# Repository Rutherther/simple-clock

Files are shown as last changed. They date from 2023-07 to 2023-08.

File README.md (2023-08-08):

# Simple clock
This is just a small project that aims to make a simple clock, using STM32F103C8T6.
The clock will be shown on a seven segment display. There will be multiple modes to show
on the clock display.

## HW
STM32F103C8T6 is used as the _brains_. It has RTC that may be powered by CR2032 battery.
It's connected to a USB header, allowing to communicate with a computer. The chip is capable
of being a device, only, not host.
There is a header with 3V3, SWDIO, SWCLK, GND to allow programming the chip using a tool such as STLink.
ASM1117-3.3 is used for stepping down from 5V to 3V3.
3V3 should not be connected whilst USB is connected as well. This would short output of the LDO to 3V3.
There is no protection!

There are 8 seven segment displays,
4 of them are blue, 4 of them are yellow, the whole display looks like this: Y.Y.BB:BBY.Y.
(Y for yellow digit, B for blue digit)
There are 4 LEDs and 4 buttons, the LEDs are next to the buttons, making each LED "associated" with a button.
That makes it possible to light up an LED next to button, if the button is pressed etc.

The digits of the seven segment display are connected to PNP transistors.
When pulling the pin connected to the transistor low, the digit is turned on.
The pins used may be connected to timers, and PWM may be utilized to set
brightness.
Segments get turned on by being low as well.

Mapping of pins to peripherals is documented in [pins](docs/pins.md).

## Features / Roadmap

- [x] Remember date, time
  - [x] Time
  - [x] Date
- [x] Set time and date using simple interface
- [x] Switch between view modes by button
- [x] Show time, date
- [x] Adjust brightness using PWM
- [x] Auto adjust brightness based on time
- [ ] Stopwatch
- [ ] USB communication
  - [ ] Set time, Get time
  - [ ] Show arbitrary text or number on the display
  - [ ] Start stopwatch
  
## Usage
The clock has two modes, default mode, and edit mode.
Default mode displays the current time, edit mode is
for editing the current time.

### Default mode
This is entered upon reset. Upon startup,
it displays only current time as hours and minutes.

First button may change the current view, there are
four views.
1. time - hours and minutes only
2. time - with seconds
3. time and date - hours, minutes, day in month and month
4. date - year, day in month and month

The second button switches to edit mode.

Third and fourth buttons change brightness.
The brightness is normally automatically adjusted
based on the current time set on the clock.
It may be temporarily changed using these buttons.
The change will last 30 minutes.
Third button decreases brightness, fourth increases it.

### Edit mode
In the edit mode, it's possible to change the time and date.
Upon entering edit mode, hours will be selected to be changed.

The currently selected field will blink. To select the next field,
the first button should be used. The order of the fields edited is:
hours, minutes, seconds, year, month, day.

To increment or decrement the current field, second and third
buttons should be used, respectively.

To save the time and date, fourth button does the job.
It may be pressed when editing any field.

When in the edit mode, the time is paused. If you enter the
edit mode by accident, the clock will probably get behind,
because a couple of seconds will pass before you exit the edit mode.

## Images of the clock
### Front, off
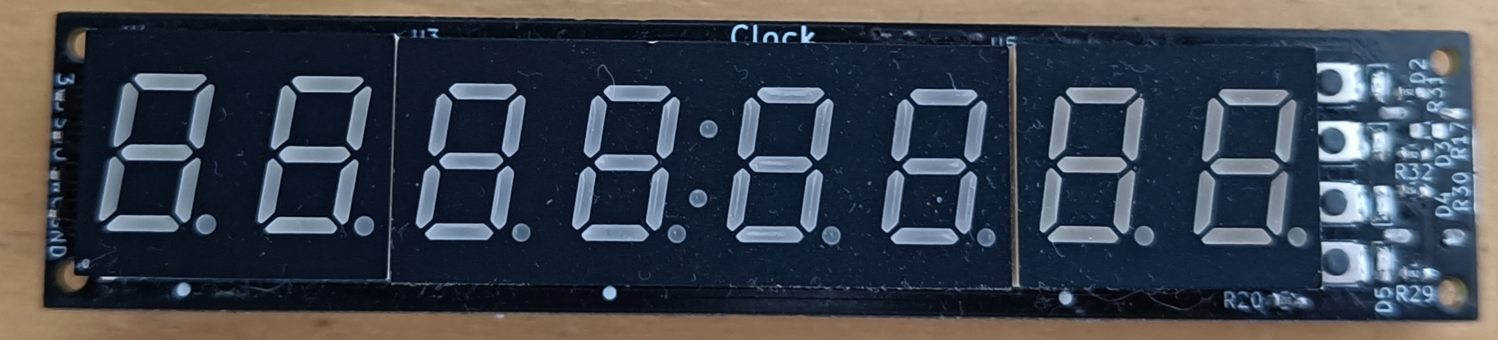
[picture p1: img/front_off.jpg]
Front, off


### Back
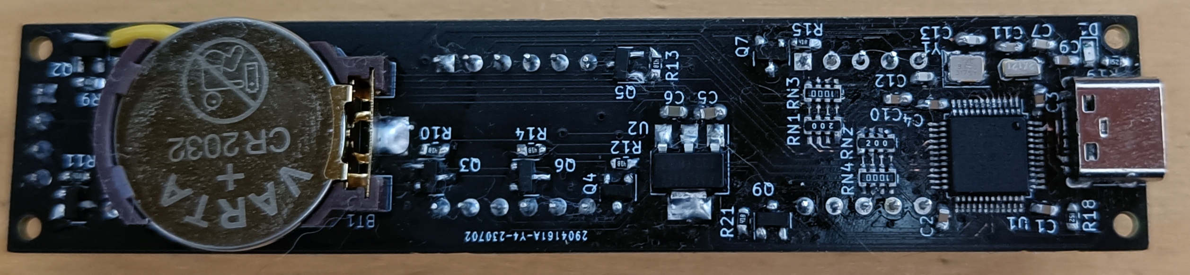
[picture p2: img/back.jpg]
Back


### Front, with seconds
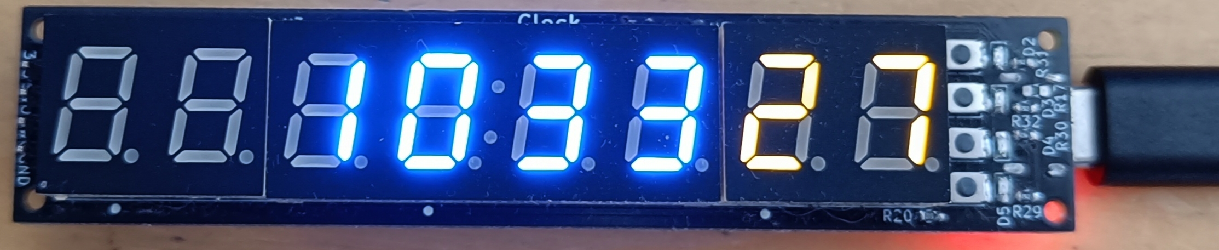
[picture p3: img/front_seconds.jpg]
Front, with seconds


### Front, with clock and date
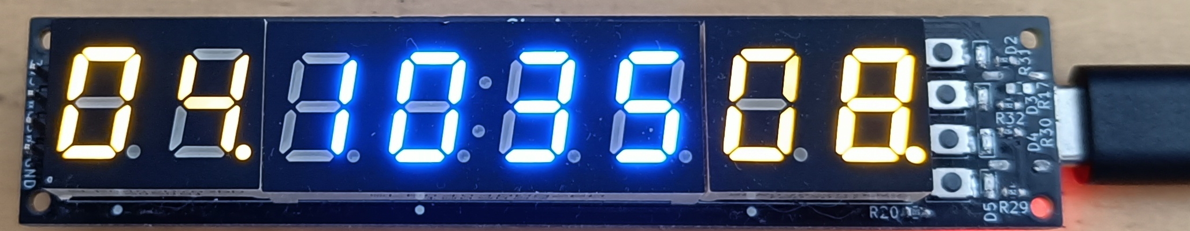
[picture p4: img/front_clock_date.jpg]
Front, clock and date


## What's next
Unfortunately, I did not solder the USB correctly on my board, so I cannot
currently test sending and receiving data using the USB, that is the reason
why the current program does not even support USB. In the future, the firmware
should support USB communication and a program for a computer should be made,
with some kind of CLI for communication with the board.

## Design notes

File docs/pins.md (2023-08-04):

# Pin mapping

## LEDs
LED1 PB12
LED2 PB11
LED3 PB1
LED4 PB0

## Buttons
SW1 PB15
SW2 PB14
SW3 PB13
SW4 PC13

## Seven segment display
The display pins are supposed to all be open-drains.
Individual segment is lit up by putting both the digit and segment on.
Only one digit at a time is supposed to be lit up, by turning
on multiple digits, it's possible.

DIG1 PA6  TIM3 CH1
DIG2 PA3  TIM2 CH4
DIG3 PA7  TIM3 CH2
DIG4 PA8  TIM1 CH1
DIG5 PA9  TIM1 CH2
DIG6 PA2  TIM2 CH3
DIG7 PA10 TIM1 CH3
DIG8 PA1  TIM2 CH2

A PB10
B PB2
C PB8
D PB6
E PB9
F PB3
G PB4
DP PB7

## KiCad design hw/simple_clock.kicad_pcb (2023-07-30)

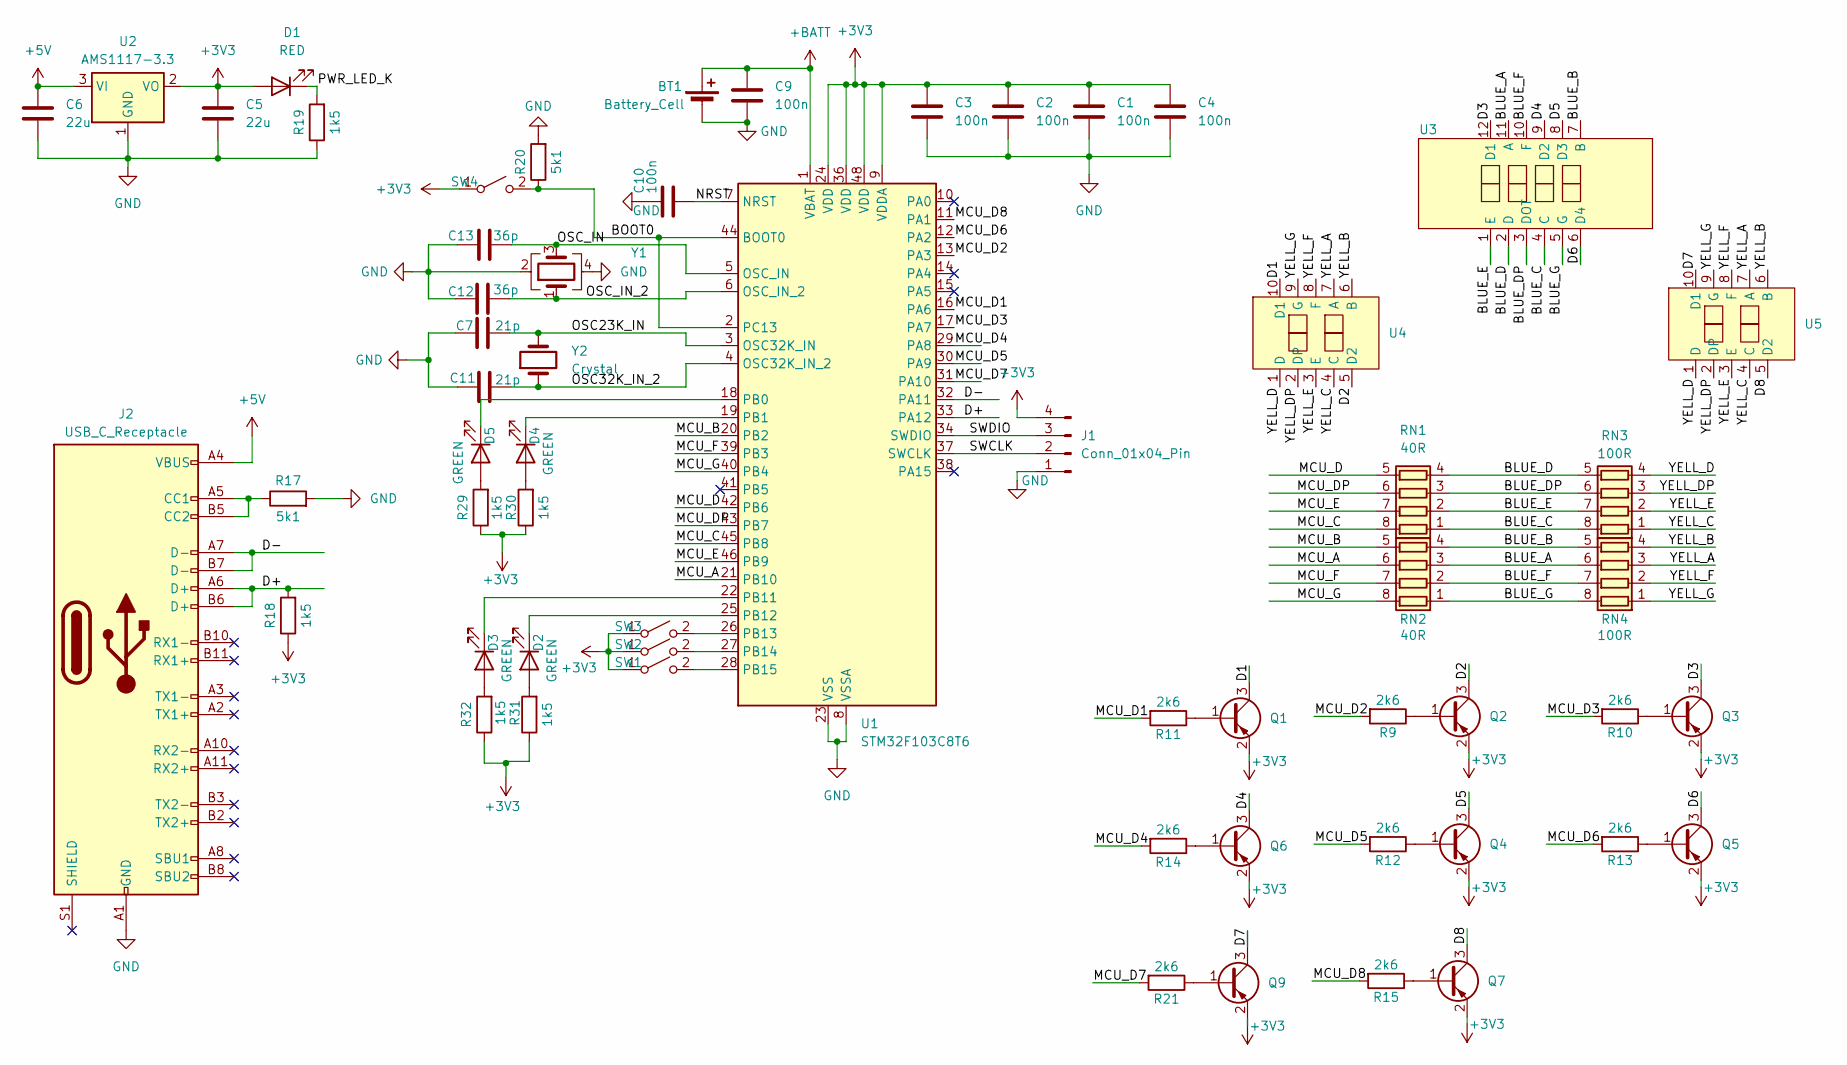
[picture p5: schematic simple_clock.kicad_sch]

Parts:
BT1: Battery_Cell; Q&J BS-8-1
C1, C2, C3, C4, C9, C10: 100n; C_0603_1608Metric
C5, C6: 22u; C_0603_1608Metric
C7, C11: 21p; C_0603_1608Metric
C12, C13: 36p; C_0603_1608Metric
D1: RED; LED_0603_1608Metric
D2, D3, D4, D5: GREEN; LED_0603_1608Metric
J1: Conn_01x04_Pin; PinHeader_1x04_P2.54mm_Vertical
J2: USB_C_Receptacle; USB_C_Receptacle_XKB_U262-16XN-4BVC11
Q1, Q2, Q3, Q4, Q5, Q6, Q7, Q9: Q_PNP_BEC; SOT-23
R9, R10, R11, R12, R13, R14, R15, R21: 2k6; R_0603_1608Metric
R17, R20: 5k1; R_0603_1608Metric
R18, R19, R29, R30, R31, R32: 1k5; R_0603_1608Metric
RN1, RN2: 40R; R_Array_Concave_4x0603
RN3, RN4: 100R; R_Array_Concave_4x0603
SW1, SW2, SW3, SW4: SW_SPST; TS-1088-AR02016
U1: STM32F103C8T6; LQFP-48_7x7mm_P0.5mm
U2: AMS1117-3.3; SOT-223-3_TabPin2
U3: SLR0404DBA2BD
U4, U5: SLR0402DYA3BD
Y1: Crystal_GND24; Crystal_SMD_3225-4Pin_3.2x2.5mm
Y2: Crystal; Crystal_SMD_3215-2Pin_3.2x1.5mm

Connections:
+3V3: C1.1, C2.1, C3.1, C4.1, C5.1, D1.2 (A), J1.4, Q1.2 (E), Q2.2 (E), Q3.2 (E), Q4.2 (E), Q5.2 (E), Q6.2 (E), Q7.2 (E), Q9.2 (E), R18.1, R29.1, R30.1, R31.1, R32.1, SW1.1 (A), SW2.1 (A), SW3.1 (A), SW4.1 (A), U1.9 (VDDA), U1.24 (VDD), U1.36 (VDD), U1.48 (VDD), U2.2 (VO)
+5V: C6.1, J2.A4 (VBUS), J2.A9 (VBUS), J2.B4 (VBUS), J2.B9 (VBUS), U2.3 (VI)
+BATT: BT1.1 (+), C9.1, U1.1 (VBAT)
/BLUE_A: RN2.3 (R3.1), RN4.6 (R3.2), U3.11 (A)
/BLUE_B: RN2.4 (R4.1), RN4.5 (R4.2), U3.7 (B)
/BLUE_C: RN1.1 (R1.1), RN3.8 (R1.2), U3.4 (C)
/BLUE_D: RN1.4 (R4.1), RN3.5 (R4.2), U3.2 (D)
/BLUE_DP: RN1.3 (R3.1), RN3.6 (R3.2), U3.3 (DOT)
/BLUE_E: RN1.2 (R2.1), RN3.7 (R2.2), U3.1 (E)
/BLUE_F: RN2.2 (R2.1), RN4.7 (R2.2), U3.10 (F)
/BLUE_G: RN2.1 (R1.1), RN4.8 (R1.2), U3.5 (G)
/BOOT0: R20.1, SW4.2 (B), U1.2 (PC13), U1.44 (BOOT0)
/D1: Q1.3 (C), U4.10 (D1)
/D2: Q2.3 (C), U4.5 (D2)
/D3: Q3.3 (C), U3.12 (D1)
/D4: Q6.3 (C), U3.9 (D2)
/D5: Q4.3 (C), U3.8 (D3)
/D6: Q5.3 (C), U3.6 (D4)
/D7: Q9.3 (C), U5.10 (D1)
/D8: Q7.3 (C), U5.5 (D2)
/D+: J2.A6 (D+), J2.B6 (D+), R18.2, U1.33 (PA12)
/D-: J2.A7 (D-), J2.B7 (D-), U1.32 (PA11)
/MCU_A: RN2.6 (R3.2), U1.21 (PB10)
/MCU_B: RN2.5 (R4.2), U1.20 (PB2)
/MCU_C: RN1.8 (R1.2), U1.45 (PB8)
/MCU_D: RN1.5 (R4.2), U1.42 (PB6)
/MCU_D1: R11.2, U1.16 (PA6)
/MCU_D2: R9.2, U1.13 (PA3)
/MCU_D3: R10.2, U1.17 (PA7)
/MCU_D4: R14.2, U1.29 (PA8)
/MCU_D5: R12.2, U1.30 (PA9)
/MCU_D6: R13.2, U1.12 (PA2)
/MCU_D7: R21.2, U1.31 (PA10)
/MCU_D8: R15.2, U1.11 (PA1)
/MCU_DP: RN1.6 (R3.2), U1.43 (PB7)
/MCU_E: RN1.7 (R2.2), U1.46 (PB9)
/MCU_F: RN2.7 (R2.2), U1.39 (PB3)
/MCU_G: RN2.8 (R1.2), U1.40 (PB4)
/NRST: C10.2, U1.7 (NRST)
/OSC23K_IN: C7.2, U1.3 (OSC32K_IN), Y2.2
/OSC32K_IN_2: C11.2, U1.4 (OSC32K_IN_2), Y2.1
/OSC_IN_2: C12.2, U1.6 (OSC_IN_2), Y1.1
/PWR_LED_K: D1.1 (K), R19.2
/SWCLK: J1.2, U1.37 (SWCLK)
/SWDIO: J1.3, U1.34 (SWDIO)
/YELL_A: RN4.3 (R3.1), U4.7 (A), U5.7 (A)
/YELL_B: RN4.4 (R4.1), U4.6 (B), U5.6 (B)
/YELL_C: RN3.1 (R1.1), U4.4 (C), U5.4 (C)
/YELL_D: RN3.4 (R4.1), U4.1 (D), U5.1 (D)
/YELL_DP: RN3.3 (R3.1), U4.2 (DP), U5.2 (DP)
/YELL_E: RN3.2 (R2.1), U4.3 (E), U5.3 (E)
/YELL_F: RN4.2 (R2.1), U4.8 (F), U5.8 (F)
/YELL_G: RN4.1 (R1.1), U4.9 (G), U5.9 (G)
GND: BT1.2 (-), C1.2, C2.2, C3.2, C4.2, C5.2, C6.2, C7.1, C9.2, C10.1, C11.1, C12.1, C13.1, J1.1, J2.A1 (GND), J2.A12 (GND), J2.B1 (GND), J2.B12 (GND), R17.2, R19.1, R20.2, U1.8 (VSSA), U1.23 (VSS), U1.35 (VSS), U1.47 (VSS), U2.1 (GND), Y1.2, Y1.4
unnamed: D2.2 (A), R31.2
unnamed: D2.1 (K), U1.25 (PB12)
unnamed: D3.2 (A), R32.2
unnamed: D3.1 (K), U1.22 (PB11)
unnamed: D4.2 (A), R30.2
unnamed: D4.1 (K), U1.19 (PB1)
unnamed: D5.2 (A), R29.2
unnamed: D5.1 (K), U1.18 (PB0)
unnamed: J2.A5 (CC1), J2.B5 (CC2), R17.1
unnamed: Q1.1 (B), R11.1
unnamed: Q2.1 (B), R9.1
unnamed: Q3.1 (B), R10.1
unnamed: Q4.1 (B), R12.1
unnamed: Q5.1 (B), R13.1
unnamed: Q6.1 (B), R14.1
unnamed: Q7.1 (B), R15.1
unnamed: Q9.1 (B), R21.1
unnamed: SW1.2 (B), U1.28 (PB15)
unnamed: SW2.2 (B), U1.27 (PB14)
unnamed: SW3.2 (B), U1.26 (PB13)
unnamed: C13.2, U1.5 (OSC_IN), Y1.3

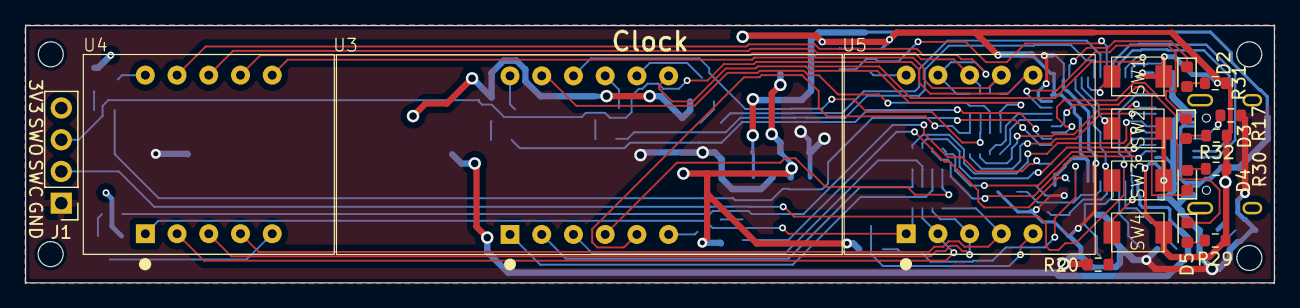
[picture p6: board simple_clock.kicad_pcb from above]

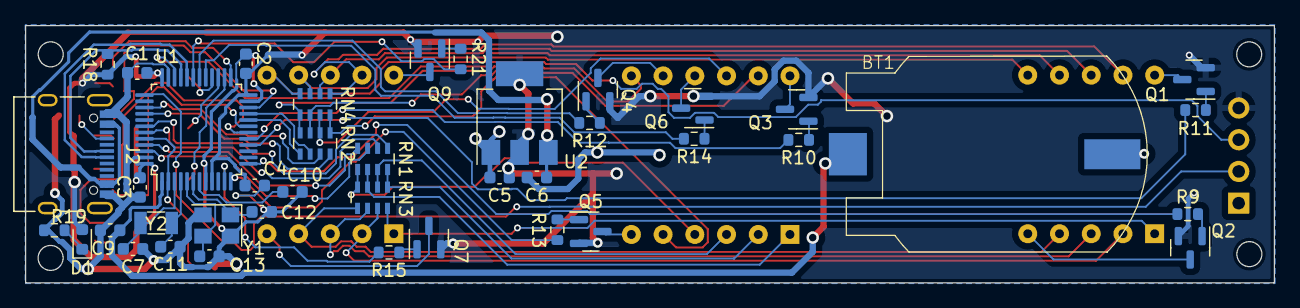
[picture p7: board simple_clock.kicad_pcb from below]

Board: 2 copper layers, 100.0 x 20.6 mm, 59 parts (41 on the bottom side), 75 nets.

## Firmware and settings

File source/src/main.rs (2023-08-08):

#![no_std]
#![no_main]
#![feature(alloc_error_handler)]
#![feature(variant_count)]
#![feature(adt_const_params)]

extern crate alloc;

pub mod brightness_manager;
pub mod button;
pub mod calendar;
pub mod clock_app;
pub mod clock_display;
pub mod clock_display_viewer;
pub mod clock_state;
pub mod count_down;
pub mod display;
pub mod linear_interpolation;
pub mod mono_timer;
pub mod number_digits;
pub mod seven_segments;
pub mod app_mode;

use alloc::boxed::Box;
use button::{ActiveHigh, Button, ButtonState};
use calendar::Calendar;
use clock_app::{ClockApp, ClockInterrupt};
use clock_display::{ClockDisplay, DisplayPart};
use clock_display_viewer::{ClockDisplayViewer, DisplayView};
use clock_state::ClockState;
use core::{alloc::Layout, cell::RefCell, convert::Infallible, panic::PanicInfo};
use cortex_m::asm::wfi;
use cortex_m_rt::entry;
use count_down::{CountDown, CountDowner};
use critical_section::Mutex;
use display::Display;
use embedded_alloc::Heap;
use embedded_hal::digital::v2::OutputPin;
use fugit::MicrosDurationU32;
use stm32f1xx_hal::{
    afio::MAPR,
    gpio::{Cr, Floating, Input, Pin},
    pac,
    pac::interrupt,
    prelude::*,
    rcc::Clocks,
    rtc::{
        RestoredOrNewRtc::{New, Restored},
        Rtc,
    },
    time::MonoTimer,
    timer::{Event, SysDelay, Tim1NoRemap, Tim2NoRemap, Tim3NoRemap, TimerExt},
};

use defmt_rtt as _;

#[global_allocator]
static HEAP: Heap = Heap::empty();

static APP: Mutex<RefCell<Option<ClockApp>>> = Mutex::new(RefCell::new(Option::None));

#[interrupt]
fn RTC() {
    critical_section::with(|cs| {
        let mut app = APP.borrow_ref_mut(cs);
        let app = app.as_mut().unwrap();

        app.interrupt(ClockInterrupt::Rtc);
    });
}

#[interrupt]
fn TIM4() {
    critical_section::with(|cs| {
        let mut app = APP.borrow_ref_mut(cs);
        let app = app.as_mut().unwrap();

        app.interrupt(ClockInterrupt::DisplayTimer);
    });
}

/// Puts given pins into open drain,
/// then makes PWM out of digit pins,
/// lastly, timer 4 is constructed for refreshing the display,
/// and ClockDisplayViewer is created.
fn init_segment_display(
    pb10: Pin<'B', 10, Input<Floating>>,
    pb2: Pin<'B', 2, Input<Floating>>,
    pb8: Pin<'B', 8, Input<Floating>>,
    pb6: Pin<'B', 6, Input<Floating>>,
    pb9: Pin<'B', 9, Input<Floating>>,
    pb3: Pin<'B', 3, Input<Floating>>,
    pb4: Pin<'B', 4, Input<Floating>>,
    pb7: Pin<'B', 7, Input<Floating>>,
    pa6: Pin<'A', 6, Input<Floating>>,
    pa3: Pin<'A', 3, Input<Floating>>,
    pa7: Pin<'A', 7, Input<Floating>>,
    pa8: Pin<'A', 8, Input<Floating>>,
    pa9: Pin<'A', 9, Input<Floating>>,
    pa2: Pin<'A', 2, Input<Floating>>,
    pa10: Pin<'A', 10, Input<Floating>>,
    pa1: Pin<'A', 1, Input<Floating>>,
    tim1: pac::TIM1,
    tim2: pac::TIM2,
    tim3: pac::TIM3,
    tim4: pac::TIM4,
    gpioa_crl: &mut Cr<'A', false>,
    gpioa_crh: &mut Cr<'A', true>,
    gpiob_crl: &mut Cr<'B', false>,
    gpiob_crh: &mut Cr<'B', true>,
    afio_mapr: &mut MAPR,
    clocks: &Clocks,
) -> ClockDisplayViewer {
    let a = pb10.into_open_drain_output(gpiob_crh);
    let b = pb2.into_open_drain_output(gpiob_crl);
    let c = pb8.into_open_drain_output(gpiob_crh);
    let d = pb6.into_open_drain_output(gpiob_crl);
    let e = pb9.into_open_drain_output(gpiob_crh);
    let f = pb3.into_open_drain_output(gpiob_crl);
    let g = pb4.into_open_drain_output(gpiob_crl);
    let dpp = pb7.into_open_drain_output(gpiob_crl);

    let dig1 = pa6.into_alternate_open_drain(gpioa_crl);
    let dig2 = pa3.into_alternate_open_drain(gpioa_crl);
    let dig3 = pa7.into_alternate_open_drain(gpioa_crl);
    let dig4 = pa8.into_alternate_open_drain(gpioa_crh);
    let dig5 = pa9.into_alternate_open_drain(gpioa_crh);
    let dig6 = pa2.into_alternate_open_drain(gpioa_crl);
    let dig7 = pa10.into_alternate_open_drain(gpioa_crh);
    let dig8 = pa1.into_alternate_open_drain(gpioa_crl);

    let pwm_freq = 2.kHz();
    let pins1 = (dig4, dig5, dig7);
    let pwm1 = tim1.pwm_hz::<Tim1NoRemap, _, _>(pins1, afio_mapr, pwm_freq, &clocks);

    let pins2 = (dig8, dig6, dig2);
    let pwm2 = tim2.pwm_hz::<Tim2NoRemap, _, _>(pins2, afio_mapr, pwm_freq, &clocks);

    let pins3 = (dig1, dig3);
    let pwm3 = tim3.pwm_hz::<Tim3NoRemap, _, _>(pins3, afio_mapr, pwm_freq, &clocks);

    let mut tim4 = tim4.counter_us(&clocks);
    tim4.listen(Event::Update);
    tim4.start(10.micros()).unwrap();

    let countdown: Box<dyn CountDown<Time = MicrosDurationU32> + Send> =
        Box::new(CountDowner::new(tim4));

    let (dig4, dig5, dig7) = pwm1.split();
    let (dig8, dig6, dig2) = pwm2.split();
    let (dig1, dig3) = pwm3.split();

    let display = Display::<8>::new(
        [
            Box::new(a),
            Box::new(b),
            Box::new(c),
            Box::new(d),
            Box::new(e),
            Box::new(f),
            Box::new(g),
            Box::new(dpp),
        ],
        [
            Box::new(dig1),
            Box::new(dig2),
            Box::new(dig3),
            Box::new(dig4),
            Box::new(dig5),
            Box::new(dig6),
            Box::new(dig7),
            Box::new(dig8),
        ],
        countdown,
    );

    let display = ClockDisplay::new(display);
    ClockDisplayViewer::new(display)
}

fn init_buttons(
    pb15: Pin<'B', 15, Input<Floating>>,
    pb14: Pin<'B', 14, Input<Floating>>,
    pb13: Pin<'B', 13, Input<Floating>>,
    pc13: Pin<'C', 13, Input<Floating>>,
    gpiob_crh: &mut Cr<'B', true>,
    gpioc_crh: &mut Cr<'C', true>,
) -> [Button<ActiveHigh>; 4] {
    let btn1 = Button::<ActiveHigh>::new(Box::new(pb15.into_pull_down_input(gpiob_crh)));
    let btn2 = Button::<ActiveHigh>::new(Box::new(pb14.into_pull_down_input(gpiob_crh)));
    let btn3 = Button::<ActiveHigh>::new(Box::new(pb13.into_pull_down_input(gpiob_crh)));
    let btn4 = Button::<ActiveHigh>::new(Box::new(pc13.into_pull_down_input(gpioc_crh)));

    [btn1, btn2, btn3, btn4]
}

fn init_leds<'a>(
    pb12: Pin<'B', 12, Input<Floating>>,
    pb11: Pin<'B', 11, Input<Floating>>,
    pb1: Pin<'B', 1, Input<Floating>>,
    pb0: Pin<'B', 0, Input<Floating>>,
    gpiob_crl: &mut Cr<'B', false>,
    gpiob_crh: &mut Cr<'B', true>,
) -> [Box<dyn OutputPin<Error = Infallible> + Send>; 4] {
    let led1 = pb12.into_open_drain_output(gpiob_crh);
    let led2 = pb11.into_open_drain_output(gpiob_crh);
    let led3 = pb1.into_open_drain_output(gpiob_crl);
    let led4 = pb0.into_open_drain_output(gpiob_crl);

    [
        Box::new(led1),
        Box::new(led2),
        Box::new(led3),
        Box::new(led4),
    ]
}

fn init_heap() {
    use core::mem::MaybeUninit;
    const HEAP_SIZE: usize = 512;
    static mut HEAP_MEM: [MaybeUninit<u8>; HEAP_SIZE] = [MaybeUninit::uninit(); HEAP_SIZE];
    unsafe { HEAP.init(HEAP_MEM.as_ptr() as usize, HEAP_SIZE) }
}

#[entry]
fn main() -> ! {
    init_heap();

    let cp = cortex_m::Peripherals::take().unwrap();
    let dp = pac::Peripherals::take().unwrap();

    let mut pwr = dp.PWR;
    let mut flash = dp.FLASH.constrain();
    let rcc = dp.RCC.constrain();
    let mut backup_domain = rcc.bkp.constrain(dp.BKP, &mut pwr);

    let clocks = rcc
        .cfgr
        .use_hse(8.MHz())
        .sysclk(24.MHz())
        .pclk1(24.MHz())
        .pclk2(24.MHz())
        .freeze(&mut flash.acr);

    let mut gpiob = dp.GPIOB.split();
    let mut gpioa = dp.GPIOA.split();
    let mut gpioc = dp.GPIOC.split();
    let mut afio = dp.AFIO.constrain();
    let (_, pb3, pb4) = afio.mapr.disable_jtag(gpioa.pa15, gpiob.pb3, gpiob.pb4);

    let leds = init_leds(
        gpiob.pb12,
        gpiob.pb11,
        gpiob.pb1,
        gpiob.pb0,
        &mut gpiob.crl,
        &mut gpiob.crh,
    );
    let btns = init_buttons(
        gpiob.pb15,
        gpiob.pb14,
        gpiob.pb13,
        gpioc.pc13,
        &mut gpiob.crh,
        &mut gpioc.crh,
    );

    let mut display = init_segment_display(
        gpiob.pb10,
        gpiob.pb2,
        gpiob.pb8,
        gpiob.pb6,
        gpiob.pb9,
        pb3,
        pb4,
        gpiob.pb7,
        gpioa.pa6,
        gpioa.pa3,
        gpioa.pa7,
        gpioa.pa8,
        gpioa.pa9,
        gpioa.pa2,
        gpioa.pa10,
        gpioa.pa1,
        dp.TIM1,
        dp.TIM2,
        dp.TIM3,
        dp.TIM4,
        &mut gpioa.crl,
        &mut gpioa.crh,
        &mut gpiob.crl,
        &mut gpiob.crh,
        &mut afio.mapr,
        &clocks,
    );
    display.set_current_view(DisplayView::ClockView);

    let mut rtc = match Rtc::restore_or_new(dp.RTC, &mut backup_domain) {
        Restored(rtc) => rtc,
        New(rtc) => rtc,
    };
    rtc.listen_seconds();

    // Initialize the state inside of a critical section,
    // to make sure that if a second will elapse during state initialization,
    // an interrupt will be called afterwards.
    critical_section::with(|cs| {
        let current_time = rtc.current_time();
        unsafe {
            // RTC interrupt cannot be called prior APP being Some,
            // otherwise a panic would result.
            cortex_m::peripheral::NVIC::unmask(interrupt::RTC);
        }

        let state = ClockState::new(
            Calendar::from_ticks(2023, current_time),
            MonoTimer::new(cp.DWT, cp.DCB, clocks),
        );

        let app = ClockApp::new(rtc, display, state);
        APP.borrow(cs).replace(Some(app));
    });

    unsafe {
        cortex_m::peripheral::NVIC::unmask(interrupt::TIM4);
    }

    let delay = cp.SYST.delay(&clocks);
    main_loop(delay, btns, leds)
}

fn main_loop(
    mut delay: SysDelay,
    mut btns: [Button<ActiveHigh>; 4],
    mut leds: [Box<dyn OutputPin<Error = Infallible> + Send>; 4],
) -> ! {
    loop {
        for (i, btn) in btns.iter_mut().enumerate() {
            btn.update();

            if btn.is_pressed() {
                leds[i].set_low().unwrap();
            } else {
                leds[i].set_high().unwrap();
            }

            let state = btn.state();
            if state != ButtonState::Off {
                critical_section::with(|cs| {
                    let mut app = APP.borrow_ref_mut(cs);
                    let app = app.as_mut().unwrap();

                    app.handle_button(i, state);
                });
            }
        }

        delay.delay_ms(50u16);
    }
}

#[panic_handler]
fn panic(info: &PanicInfo) -> ! {
    defmt::error!("{}", defmt::Display2Format(info));
    defmt::flush();

    cortex_m::peripheral::NVIC::mask(interrupt::RTC);
    critical_section::with(|cs| {
        let mut app = APP.borrow_ref_mut(cs);
        let app = app.as_mut().unwrap();
        let display = app.display();
        display.hide_all();
        let _ = display
            .clock_display()
            .show_text(DisplayPart::MainDisplay, "Erro");
        display.clock_display().hide(DisplayPart::SideDisplay1);
        display.clock_display().hide(DisplayPart::SideDisplay2);
    });

    loop {
        wfi();
    }
}

#[alloc_error_handler]
fn oom(_: Layout) -> ! {
    cortex_m::peripheral::NVIC::mask(interrupt::RTC);
    critical_section::with(|cs| {
        let mut app = APP.borrow_ref_mut(cs);
        let app = app.as_mut().unwrap();
        let display = app.display();
        display.hide_all();
        let _ = display
            .clock_display()
            .show_text(DisplayPart::MainDisplay, "oom");
    });

    loop {
        wfi();
    }
}

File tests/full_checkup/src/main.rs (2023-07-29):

#![no_std]
#![no_main]

use core::convert::Infallible;
use embedded_hal::digital::v2::{OutputPin, InputPin};
use panic_halt as _;

use nb::block;

use cortex_m_rt::entry;
use stm32f1xx_hal::{pac, prelude::*, timer::{Timer, Tim1NoRemap, Tim2NoRemap, Tim3NoRemap, PwmChannel}, rtc::Rtc};

#[entry]
fn main() -> ! {
   // Get access to the core peripherals from the cortex-m crate
    let cp = cortex_m::Peripherals::take().unwrap();
    // Get access to the device specific peripherals from the peripheral access crate
    let dp = pac::Peripherals::take().unwrap();

    // Take ownership over the raw flash and rcc devices and convert them into the corresponding
    // HAL structs
    let mut pwr = dp.PWR;
    let mut flash = dp.FLASH.constrain();
    let rcc = dp.RCC.constrain();
    let mut backup_domain = rcc.bkp.constrain(dp.BKP, &mut pwr);

    let mut rtc = Rtc::new(dp.RTC, &mut backup_domain);

    // Freeze the configuration of all the clocks in the system and store the frozen frequencies in
    // `clocks`
    let clocks = rcc
        .cfgr
        .use_hse(8.MHz())
        .sysclk(24.MHz())
        .pclk1(24.MHz())
        .pclk2(24.MHz())
        .freeze(&mut flash.acr);

    let mut gpiob = dp.GPIOB.split();
    let mut gpioa = dp.GPIOA.split();
    let mut gpioc = dp.GPIOC.split();
    let mut afio = dp.AFIO.constrain();

    let (_, pb3, pb4) = afio.mapr.disable_jtag(gpioa.pa15, gpiob.pb3, gpiob.pb4);

    let mut led1 = gpiob.pb12.into_open_drain_output(&mut gpiob.crh);
    let mut led2 = gpiob.pb11.into_open_drain_output(&mut gpiob.crh);
    let mut led3 = gpiob.pb1.into_open_drain_output(&mut gpiob.crl);
    let mut led4 = gpiob.pb0.into_open_drain_output(&mut gpiob.crl);

    let mut leds: [&mut dyn OutputPin<Error = Infallible>; 4] = [&mut led1, &mut led2, &mut led3, &mut led4];

    let btn1 = gpiob.pb15.into_pull_down_input(&mut gpiob.crh);
    let btn2 = gpiob.pb14.into_pull_down_input(&mut gpiob.crh);
    let btn3 = gpiob.pb13.into_pull_down_input(&mut gpiob.crh);
    let btn4 = gpioc.pc13.into_floating_input(&mut gpioc.crh);

    let btns: [&dyn InputPin<Error = Infallible>; 4] = [&btn1, &btn2, &btn3, &btn4];

    let mut a = gpiob.pb10.into_open_drain_output(&mut gpiob.crh);
    let mut b = gpiob.pb2.into_open_drain_output(&mut gpiob.crl);
    let mut c = gpiob.pb8.into_open_drain_output(&mut gpiob.crh);
    let mut d = gpiob.pb6.into_open_drain_output(&mut gpiob.crl);
    let mut e = gpiob.pb9.into_open_drain_output(&mut gpiob.crh);
    let mut f = pb3.into_open_drain_output(&mut gpiob.crl);
    let mut g = pb4.into_open_drain_output(&mut gpiob.crl);
    let mut dpp = gpiob.pb7.into_open_drain_output(&mut gpiob.crl);

    let mut segments: [&mut dyn OutputPin<Error = Infallible>; 8] = [&mut a, &mut b, &mut c, &mut d, &mut e, &mut f, &mut g, &mut dpp];

    let dig1 = gpioa.pa6.into_alternate_open_drain(&mut gpioa.crl);
    let dig2 = gpioa.pa3.into_alternate_open_drain(&mut gpioa.crl);
    let dig3 = gpioa.pa7.into_alternate_open_drain(&mut gpioa.crl);
    let dig4 = gpioa.pa8.into_alternate_open_drain(&mut gpioa.crh);
    let dig5 = gpioa.pa9.into_alternate_open_drain(&mut gpioa.crh);
    let dig6 = gpioa.pa2.into_alternate_open_drain(&mut gpioa.crl);
    let dig7 = gpioa.pa10.into_alternate_open_drain(&mut gpioa.crh);
    let dig8 = gpioa.pa1.into_alternate_open_drain(&mut gpioa.crl);

    let tim1 = Timer::new(dp.TIM1, &clocks);
    let tim2 = Timer::new(dp.TIM2, &clocks);
    let tim3 = Timer::new(dp.TIM3, &clocks);

    let pins1 = (dig4, dig5, dig7);
    let pwm1 = tim1
        .pwm_hz::<Tim1NoRemap, _, _>(pins1, &mut afio.mapr, 500.Hz());

    let pins2 = (dig8, dig6, dig2);
    let pwm2 = tim2
        .pwm_hz::<Tim2NoRemap, _, _>(pins2, &mut afio.mapr, 500.Hz());

    let pins3 = (dig1, dig3);
    let pwm3 = tim3
        .pwm_hz::<Tim3NoRemap, _, _>(pins3, &mut afio.mapr, 500.Hz());

    let (mut dig4, mut dig5, mut dig7) = pwm1.split();
    let (mut dig8, mut dig6, mut dig2) = pwm2.split();
    let (mut dig1, mut dig3) = pwm3.split();

    let mut digits: [&mut dyn _embedded_hal_PwmPin<Duty = u16>; 8] = [ &mut dig1, &mut dig2, &mut dig3, &mut dig4, &mut dig5, &mut dig6, &mut dig7, &mut dig8 ];
    for digit in digits.iter_mut() {
        // has to be enabled, when disabled, 0 is outputted, meaning digit is turned on...
        digit.enable();
        digit.set_duty(0xFFFF);
    }

    // Configure the syst timer to trigger an update every second
    let mut timer = Timer::new(dp.TIM4, &clocks).counter_hz();
    timer.start(1.Hz()).unwrap();

    let mut led_index: usize = 0;
    let mut display_stage: bool = false;
    let mut digit_index: usize = 0;
    let mut segment_index: usize = 0;
    loop {
        for (i, led) in leds.iter_mut().enumerate() {
            if i == led_index {
                led.set_low().unwrap();
            } else {
                led.set_high().unwrap();
            }
        }

        for (i, btn) in btns.iter().enumerate() {
            if btn.is_high().unwrap() {
                leds[i].set_low().unwrap(); // turn on led that is next to the button
            }
        }

        for (i, digit) in digits.iter_mut().enumerate() {
            if i == digit_index {
                digit.set_duty(0);
            } else {
                digit.set_duty(0xFFFF);
            }
        }

        if display_stage {
            for (i, segment) in segments.iter_mut().enumerate() {
                if i == segment_index {
                    segment.set_low().unwrap();
                } else {
                    segment.set_high().unwrap();
                }
            }
        } else {
            for segment in segments.iter_mut() {
                segment.set_low().unwrap();
            }
        }

        led_index = (led_index + 1) % leds.len();

        if display_stage {
            segment_index = (segment_index + 1) % segments.len();
            if segment_index == 0 {
                digit_index = (digit_index + 1) % digits.len();
            }
        } else {
            digit_index = (digit_index + 1) % digits.len();
            segment_index = 0;
        }

        if segment_index == 0 && digit_index == 0 {
            display_stage = !display_stage;
        }

        block!(timer.wait()).unwrap();
    }
}

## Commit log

2023-07-29 feat(src): add basic button representation
2023-07-29 feat(tests): add full checkup testing peripherals
    Tests all peripherals, observation should point
    out to where an error is, if any.
    [main.rs]
2023-07-30 feat(hw): add KiCAD project, schema and pcb
    [simple_clock.kicad_pcb, simple_clock.kicad_sch]
2023-07-30 fix(src): remove unnecessary import
    [main.rs]
2023-08-06 feat(src): implement Calendar::from_ticks for arbitrary year, add Calendar::to_ticks
    So far, Calendar::from_ticks could not correctly parse
    other month than the base month, this commit fixes that.
    Calendar::to_ticks may convert any Calendar date to seconds passed from
    the base year. The base year is remembered in Calendar instance.
    [main.rs]
2023-08-06 feat(src): add setter methods for Calendar
    Allows to change the current date of
    already existing calendar.
2023-08-06 feat(src): replace DisplayView with hide, show on clock parts
    The clock is meant to show only clock, so introducing
    DisplayView trait was an overkill, a simpler
    solution has been implemented instead.
    Previous solution did not allow for showing and hiding individual parts,
    hiding parts may be useful when setting time, to blink the current part
    being set.
    [main.rs]
2023-08-08 feat(src): add clock edit mode
    Adds modes for the clock app, that may be
    changed. The new mode added is clock edit mode,
    that adds support for editing the current clock.
